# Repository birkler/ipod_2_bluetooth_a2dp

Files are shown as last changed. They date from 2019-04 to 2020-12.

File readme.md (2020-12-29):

# Setup bluetooth a2dp sink

https://scribles.net/streaming-bluetooth-audio-from-phone-to-raspberry-pi-using-alsa/

https://gist.github.com/mill1000/74c7473ee3b4a5b13f6325e9994ff84c
https://gist.github.com/mill1000/74c7473ee3b4a5b13f6325e9994ff84c

sudo unzip -p 2019-04-08-raspbian-stretch-lite.zip | sudo dd of=/dev/sda bs=4M conv=fsync status=progress

# Setup and connect to zero without wifi:

https://raspberrypi.stackexchange.com/questions/73523/connect-pi-zero-via-usb-rndis-gadget-to-ubuntu-17-04

https://github.com/adrianomarto/soft_uart/blob/master/README.md

## Reroute audio to gpio header:

https://raspberrypi.stackexchange.com/questions/49600/how-to-output-audio-signals-through-gpio

https://github.com/raspberrypi/firmware/blob/master/boot/overlays/README

audremap GPIO12-GPIO13

https://raspberrypi.stackexchange.com/questions/83610/gpio-pinout-orientation-raspberypi-zero-w

#ipod interface

https://stackoverflow.com/questions/1720568/whats-needed-to-use-the-apple-accessory-protocol

https://github.com/oandrew/ipod-gadget

http://pinouts.ru/PortableDevices/ipod_pinout.shtml
https://nuxx.net/wiki/iPod_Dock_Connector

https://www.raspberrypi.org/forums/viewtopic.php?f=63&t=163182

sudo apt-get install git

sudo apt-get install python3-serial
sudo apt-get install bluealsa

sudo cp *.service /lib/systemd/system
sudo cp a2dp-agent /usr/local/bin
sudo cp ipod_emul_daemon.py /usr/local/bin

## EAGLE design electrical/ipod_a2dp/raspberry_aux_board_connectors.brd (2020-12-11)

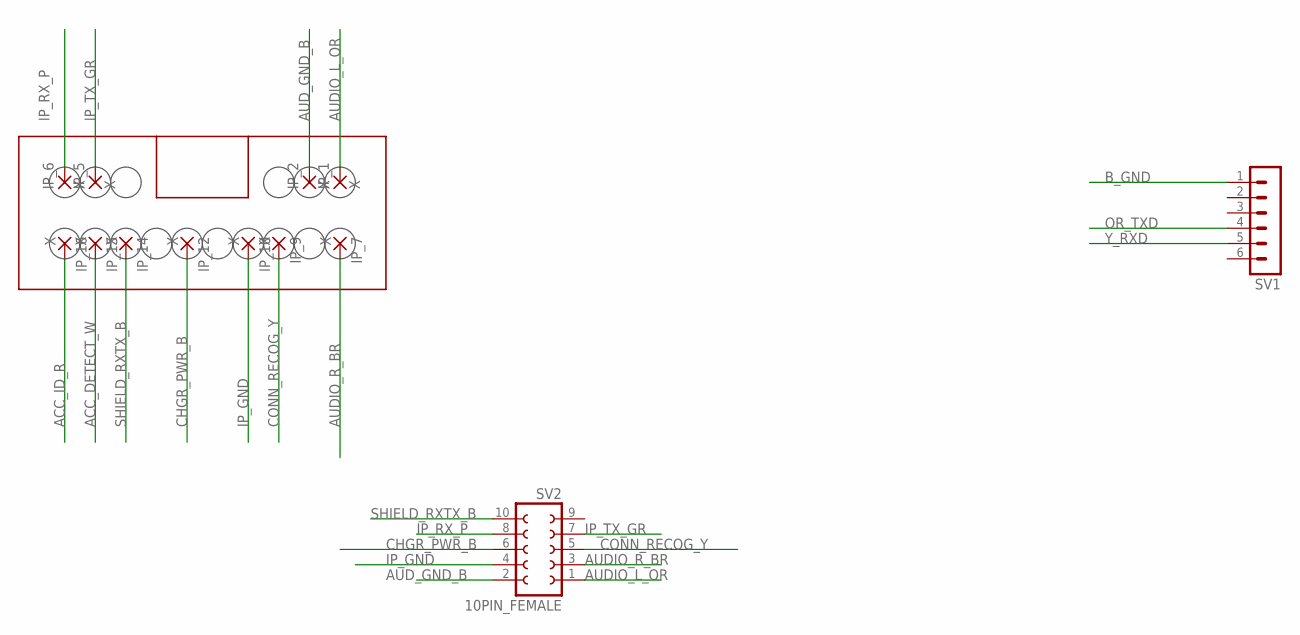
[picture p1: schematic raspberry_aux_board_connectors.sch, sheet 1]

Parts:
IP_1, IP_2, IP_5, IP_6, IP_7, IP_9, IP_10, IP_12, IP_14, IP_15, IP_16: X; 2,15/1,0
SV1: MA06-1
SV2: 10PIN_FEMALE; FE05-2

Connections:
ACC_DETECT_W: IP_15.1
ACC_ID_R: IP_16.1
AUDIO_L_OR: IP_1.1, SV2.1
AUDIO_R_BR: IP_7.1, SV2.3
AUD_GND_B: IP_2.1, SV2.2
B_GND: SV1.1
CHGR_PWR_B: IP_12.1, SV2.6
CONN_RECOG_Y: IP_9.1, SV2.5
IP_GND: IP_10.1, SV2.4
IP_RX_P: IP_6.1, SV2.8
IP_TX_GR: IP_5.1, SV2.7
OR_TXD: SV1.4
SHIELD_RXTX_B: IP_14.1, SV2.10
Y_RXD: SV1.5

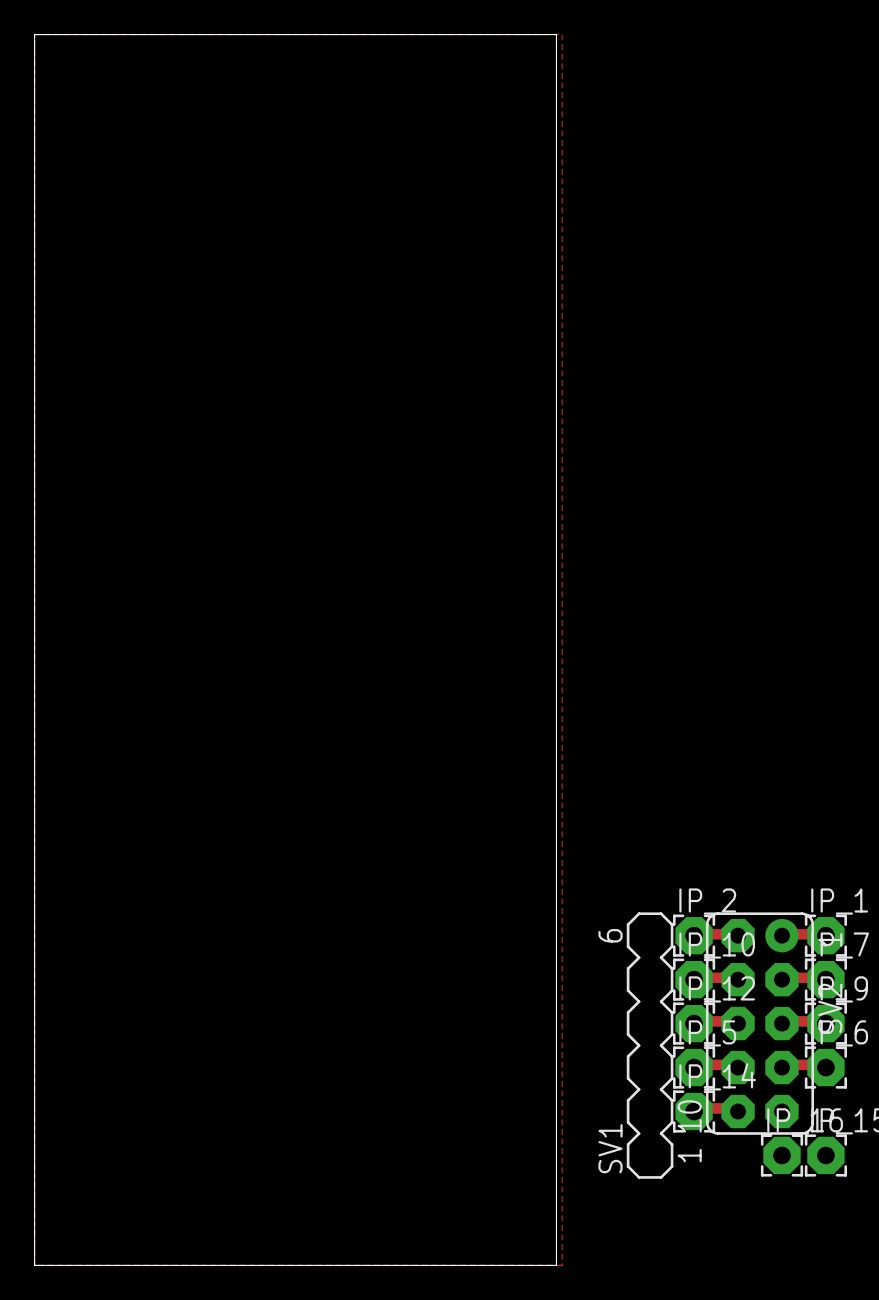
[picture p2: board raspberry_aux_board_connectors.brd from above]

Board: 2 copper layers, 30.1 x 71.1 mm, 13 parts (0 on the bottom side), 9 nets.

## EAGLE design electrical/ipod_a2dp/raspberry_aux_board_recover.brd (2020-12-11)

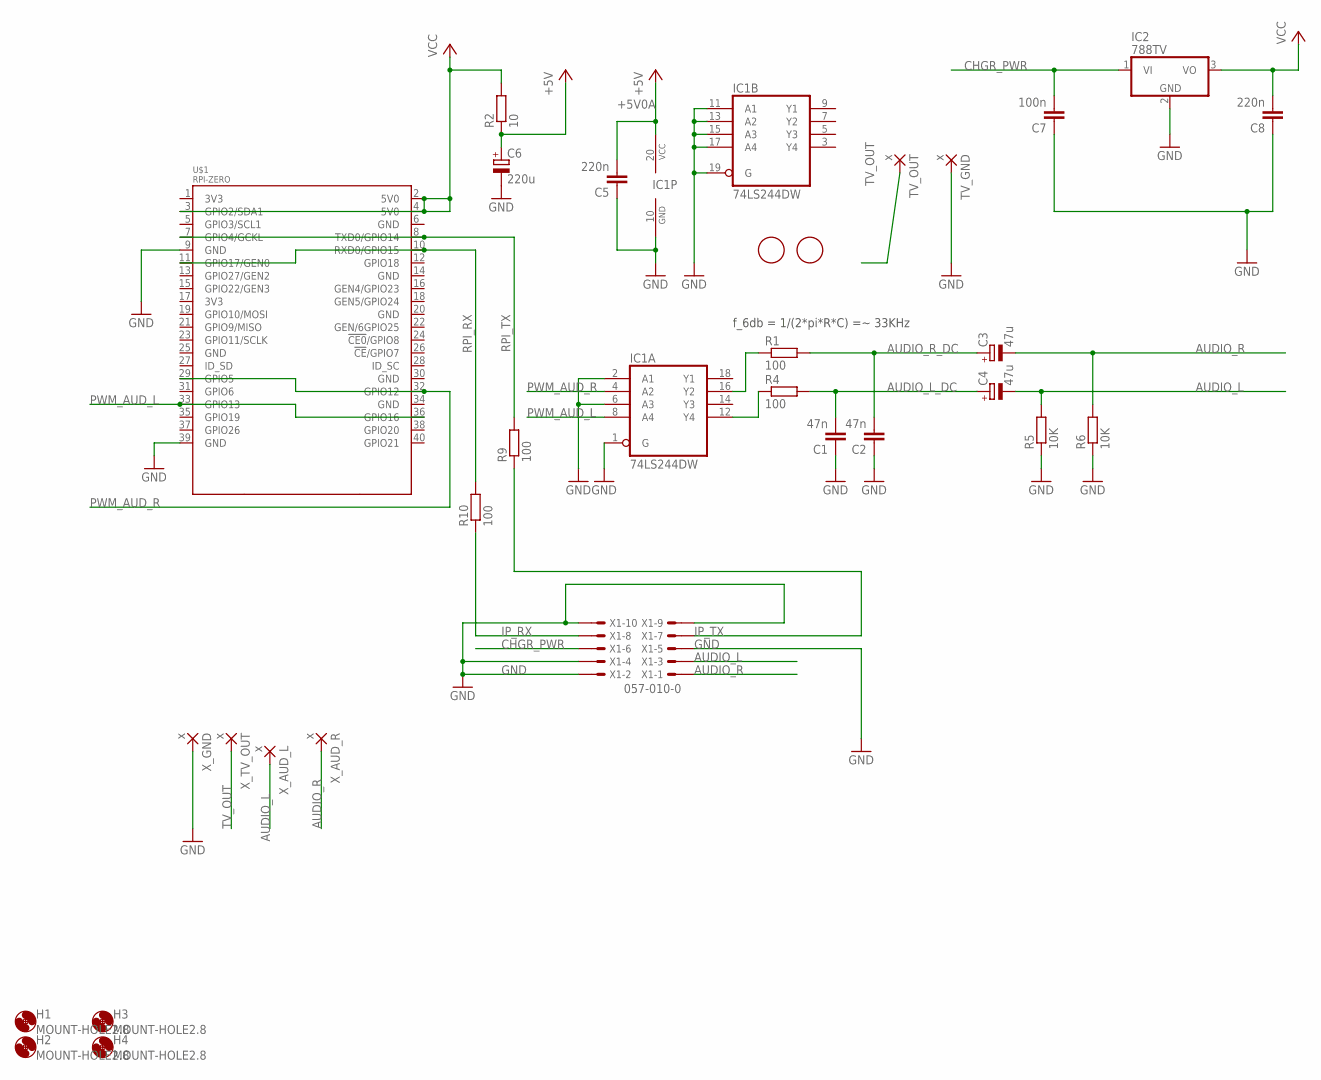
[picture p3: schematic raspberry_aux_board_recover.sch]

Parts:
C1, C2: 47n; C050-025X075
C3, C4: 47u; E2,5-5
C5, C8: 220n; C050-050X075
C6: 220u; E5-10,5
C7: 100n; C050-050X075
H1, H2, H3, H4: MOUNT-HOLE2.8; 2,8
IC1: 74LS244DW; SO20W
IC2: 788TV; TO220V
R1, R10: 100; 0207/10
R2: 10; 0204/7
R4, R9: 100; 0204/7
R5, R6: 10K; 0204/5
TV_GND: x; 2,15/1,0
TV_OUT: x; 2,15/1,0
U$1: RPI-ZERO; RASPBERRYPI_BASTELSTUBE_V13_RASPI_BOARD_B+_FULL
U$2, U$3: FIDUCIAL; FIDUCIAL_1MM
X1: 057-010-0
X_AUD_L: x; 2,15/1,0
X_AUD_R: x; 2,15/1,0
X_GND: x; 2,15/1,0
X_TV_OUT: x; 2,15/1,0

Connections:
+5V0A: C5.2, C6.+, IC1.20 (VCC), R2.1
AUDIO_L: C4.-, R5.2, X1.3, X_AUD_L.1
AUDIO_L_DC: C1.2, C4.+, R4.2
AUDIO_R: C3.-, R6.2, X1.1, X_AUD_R.1
AUDIO_R_DC: C2.2, C3.+, R1.2
CHGR_PWR: C7.2, IC2.1 (VI), X1.6
GND: C1.1, C2.1, C5.1, C6.-, C7.1, C8.1, IC1.1 (G), IC1.2 (A1), IC1.6 (A3), IC1.10 (GND), IC1.11 (A1), IC1.13 (A2), IC1.15 (A3), IC1.17 (A4), IC1.19 (G), IC2.2 (GND), R5.1, R6.1, TV_GND.1, U$1.9 (GND), U$1.39 (GND), X1.2, X1.4, X1.5, X1.9, X1.10, X_GND.1
IP_RX: R10.1, X1.8
IP_TX: R9.1, X1.7
unnamed: IC1.12 (Y4), R4.1
unnamed: IC1.16 (Y2), R1.1
PWM_AUD_L: IC1.8 (A4), U$1.33 (GPIO13), U$1.36 (GPIO16)
PWM_AUD_R: IC1.4 (A2), U$1.29 (GPIO5), U$1.32 (GPIO12)
RPI_RX: R10.2, U$1.10 (RXD0/GPIO15), U$1.11 (GPIO17/GEN0)
RPI_TX: R9.2, U$1.7 (GPIO4/GCKL), U$1.8 (TXD0/GPIO14)
TV_OUT: TV_OUT.1, X_TV_OUT.1
VCC: C8.2, IC2.3 (VO), R2.2, U$1.2 (5V0), U$1.3 (GPIO2/SDA1), U$1.4 (5V0)

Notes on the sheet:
f_6db = 1/(2*pi*R*C) =~ 33KHz

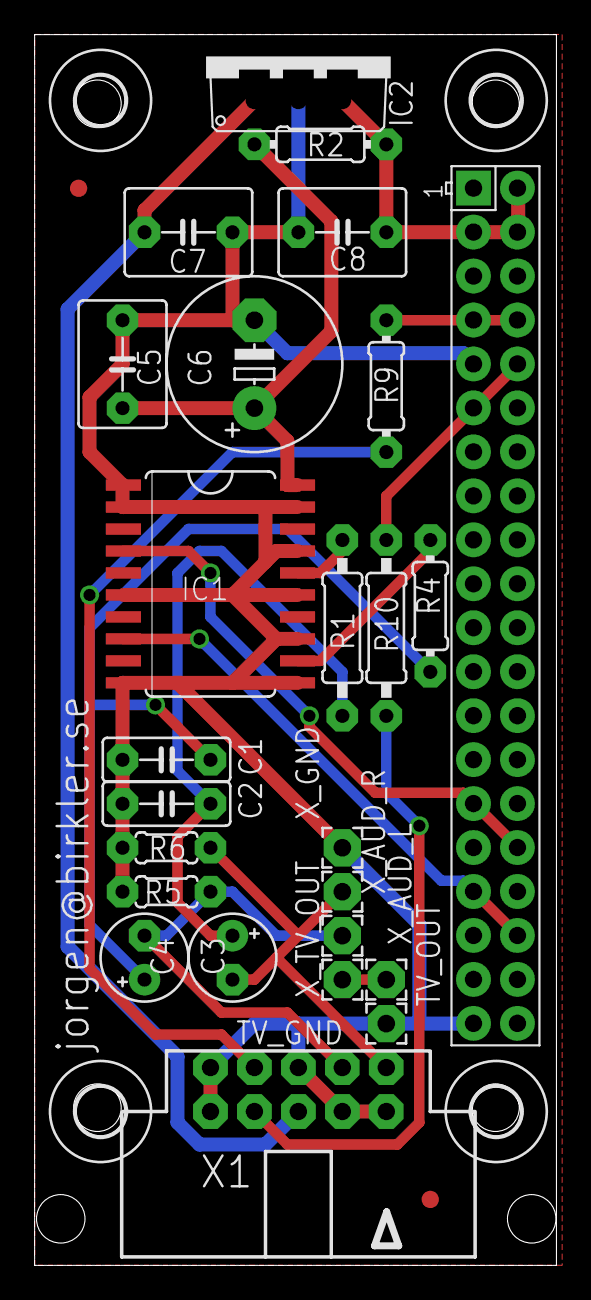
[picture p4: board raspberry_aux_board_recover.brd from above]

Board: 2 copper layers, 30.1 x 71.1 mm, 31 parts (0 on the bottom side), 17 nets.

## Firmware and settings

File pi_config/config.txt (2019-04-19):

# For more options and information see
# http://rpf.io/configtxt
# Some settings may impact device functionality. See link above for details

# uncomment if you get no picture on HDMI for a default "safe" mode
#hdmi_safe=1

# uncomment this if your display has a black border of unused pixels visible
# and your display can output without overscan
#disable_overscan=1

# uncomment the following to adjust overscan. Use positive numbers if console
# goes off screen, and negative if there is too much border
#overscan_left=16
#overscan_right=16
#overscan_top=16
#overscan_bottom=16

# uncomment to force a console size. By default it will be display's size minus
# overscan.
#framebuffer_width=1280
#framebuffer_height=720

# uncomment if hdmi display is not detected and composite is being output
#hdmi_force_hotplug=1

# uncomment to force a specific HDMI mode (this will force VGA)
#hdmi_group=1
#hdmi_mode=3

# uncomment to force a HDMI mode rather than DVI. This can make audio work in
# DMT (computer monitor) modes
#hdmi_drive=2

# uncomment to increase signal to HDMI, if you have interference, blanking, or
# no display
#config_hdmi_boost=4

# uncomment for composite PAL
#sdtv_mode=2

#uncomment to overclock the arm. 700 MHz is the default.
#arm_freq=800

# Uncomment some or all of these to enable the optional hardware interfaces
dtparam=i2c_arm=on
#dtparam=i2s=on
#dtparam=spi=on

# Uncomment this to enable the lirc-rpi module
#dtoverlay=lirc-rpi

# Additional overlays and parameters are documented /boot/overlays/README

# Enable audio (loads snd_bcm2835)
dtparam=audio=on


#Enable pwm audio output on GPIO12 and GPIO13, still output on jack if running on RPI3+
dtoverlay=audremap
dtparam=enable_jack


#dtoverlay=hd44780-lcd
#dtparam=display_height=2
#dtparam=display_width=20
#dtparam=pin_bl=21
#dtparam=pin_d7=4
#dtparam=pin_d6=18
#dtparam=pin_d5=17
#dtparam=pin_d4=27
#dtparam=pin_rs=23
#dtparam=pin_en=22

gpu_mem=64

#enable overlay for usb-ethernet gadget
dtoverlay=dwc2


#Disable wifi to stop it interferring with bluettoth a2dp
dtoverlay=pi3-disable-wifi

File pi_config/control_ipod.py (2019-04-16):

import serial
import time

ser = serial.Serial() # open serial port

ser.port = '/dev/ttyS0'

ser.baudrate = 19200
ser.bytesize = serial.EIGHTBITS
ser.parity = serial.PARITY_NONE
ser.stopbits = serial.STOPBITS_ONE
ser.timeout = 10

ser.open()
print(ser.isOpen)
print(ser.name) # check which port was really used

airmode = [0xFF,0x55,0x03,0x00,0x01,0x04,0xF8]

mode2 = [0xFF,0x55,0x03,0x00,0x01,0x02,0xFA]

pauseplay = [0xFF,0x55,0x03,0x02,0x00,0x01,0xFA]
stop = [0xFF,0x55,0x03,0x02,0x00,0x80,0xFB]
volup = [0xFF,0x55,0x03,0x02,0x00,0x02,0xF9]
voldown = [0xFF,0x55,0x03,0x02,0x00,0x04,0xF7]
play = [0xFF,0x55,0x04,0x02,0x00,0x00,0x01,0xF9]
pause = [0xFF,0x55,0x04,0x02,0x00,0x00,0x02,0xF8]

nexttrack = [0xFF,0x55,0x03,0x02,0x00,0x08,0xF3]
prevtrack = [0xFF,0x55,0x03,0x02,0x00,0x10,0xEB]

release = [0xFF,0x55,0x03,0x02,0x00,0x00,0xFB]

print('mode2')
ser.write(serial.to_bytes(mode2))
time.sleep(0.03)

print('play')
ser.write(serial.to_bytes(play)) 
time.sleep(0.03)

print('release')
ser.write(serial.to_bytes(release))
time.sleep(10)

print('nexttrack')
ser.write(serial.to_bytes(nexttrack))
time.sleep(0.03)

print('release')
ser.write(serial.to_bytes(release))
time.sleep(10)

print('pause')
ser.write(serial.to_bytes(pause))
time.sleep(0.03)

print('release')
ser.write(serial.to_bytes(release))

ser.close() # close port

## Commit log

2019-04-16 initial files.
    [config.txt, raspberry_aux_board.sch]
2019-04-19 more changes. proto tested. working for audio.
    [config.txt, raspberry_aux_board.sch, raspberry_aux_board_recover.brd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]
2019-04-23 updated board
    [raspberry_aux_board_recover.brd, raspberry_aux_board_recover.sch]
2019-04-23 update board and schematic. update daemon for ipod emul
    [raspberry_aux_board_recover.brd, raspberry_aux_board_recover.sch]
2019-04-30 updated schematic and board. sent to production
    [DRILEGEND.CFG, _saved_ipoad_a2dp.sch, ipoad_a2dp.kicad_pcb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]
2019-04-30 New CAM production with soldermask plus fixes to silkmask
    [raspberry_aux_board_recover.brd, raspberry_aux_board_recover.sch]
2020-12-11 update codez.
    [raspberry_aux_board_connectors.brd, raspberry_aux_board_connectors.sch, raspberry_aux_board_recover.brd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]
